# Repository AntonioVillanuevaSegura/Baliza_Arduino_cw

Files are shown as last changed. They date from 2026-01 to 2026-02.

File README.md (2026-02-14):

# Baliza_Arduino_cw
Modificacion del programa de EA7HG  por F4LEC , para simulacion ,

Posibilidad de cambiar WPM 
Cambio de mensaje linea 13 String mensaje = "";  //Mensaje a enviar por la baliza
Debug RS232

( entre comentarios esta el codigo para modo real , no simulacion ,  no probado )

Link a simulacion con el codigo C++ modificado 
https://wokwi.com/projects/454496346094658561

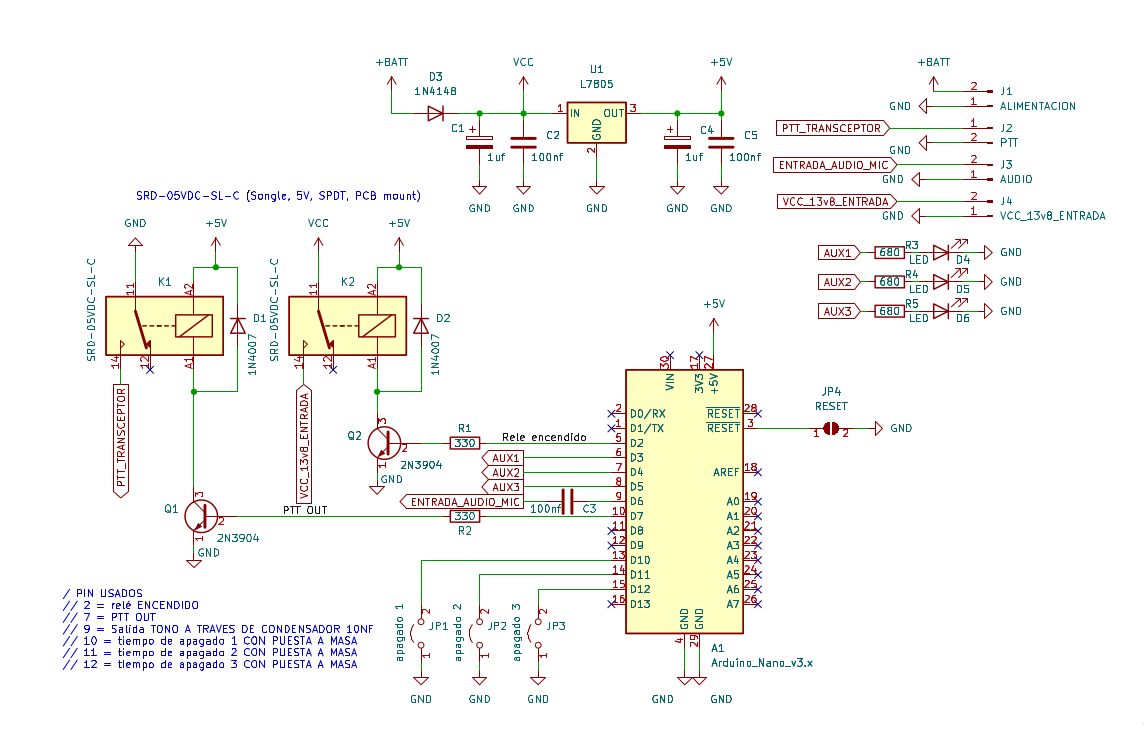
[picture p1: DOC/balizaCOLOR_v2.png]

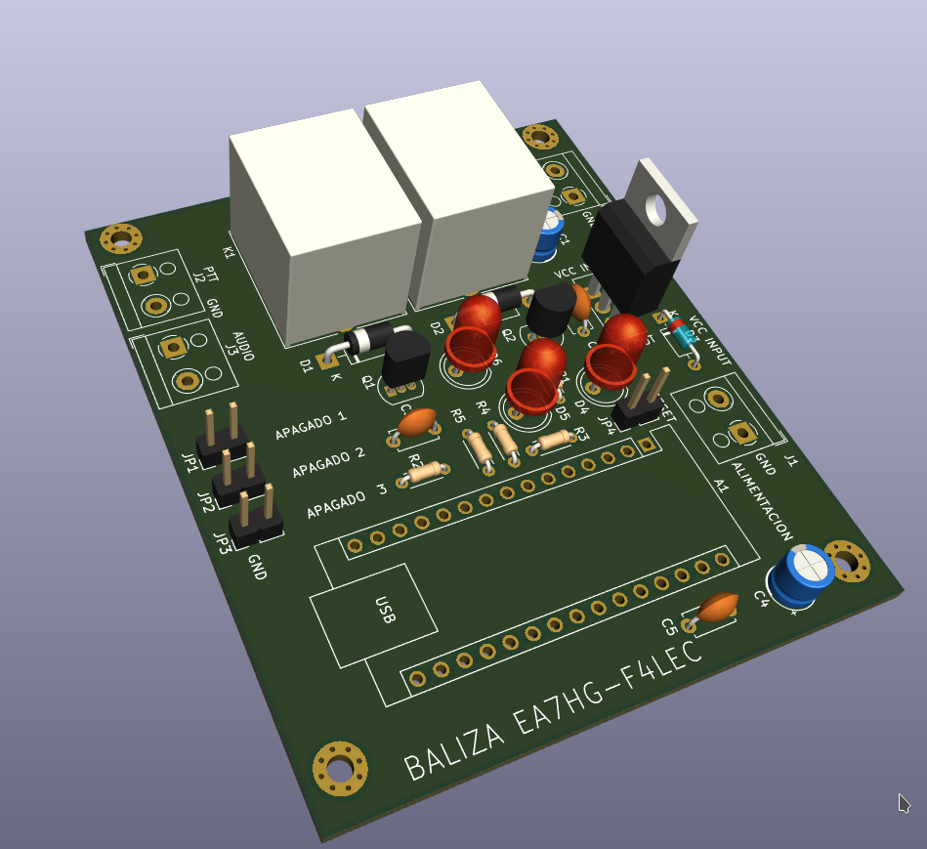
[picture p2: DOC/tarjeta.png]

Watch the video (https://youtu.be/UsDUSa7aJFM)

La tarjeta PCB tiene un diodo de proteccion de polaridad a la entrada
He previsto la PCB con 3 salidas adicionales con LED ,pero la base sigue siendo la misma 

La CPU es una Arduino nano , resistencia de 1/4 de W ....

Hay una carpeta GERBER con un fichero comprimido baliza.zip que es 
compatible con el formato de https://jlcpcb.com por ejemplo 

El tipo de rele que voy a utilizar 
PC, JQC-3F(T73), DC5V Bobine, SPDT, 7A 240VAC Bornes 5 broches
https://www.amazon.fr/dp/B074599SN8?ref=ppx_yo2ov_dt_b_fed_asin_title

Los conectores
5mm PCB Vis Connecteur, Bornier à Souder Vert, 2
https://www.amazon.fr/dp/B0DSBSXL47?ref=ppx_yo2ov_dt_b_fed_asin_title

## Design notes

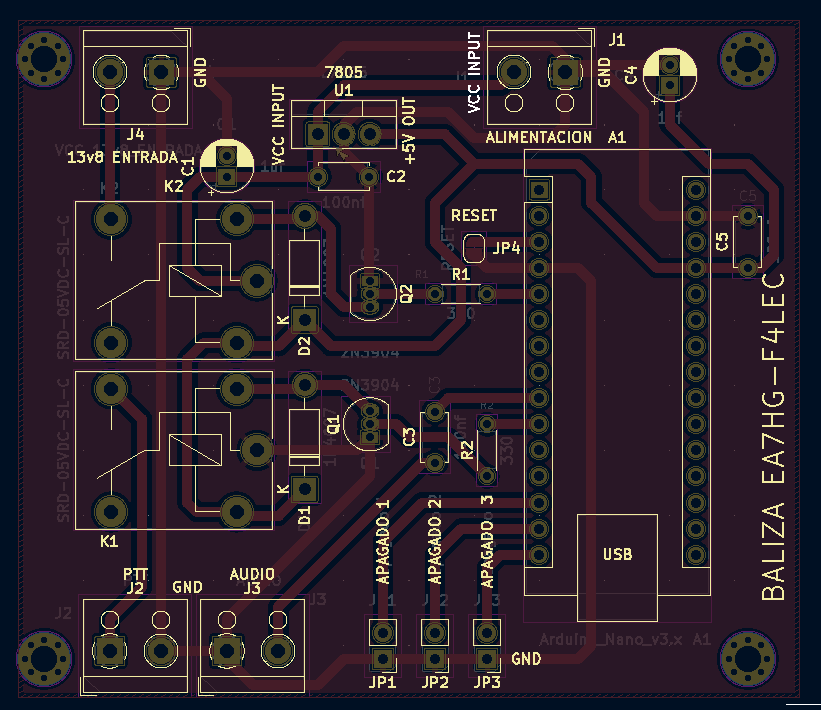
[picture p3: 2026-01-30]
DOC/tarjeta2.png

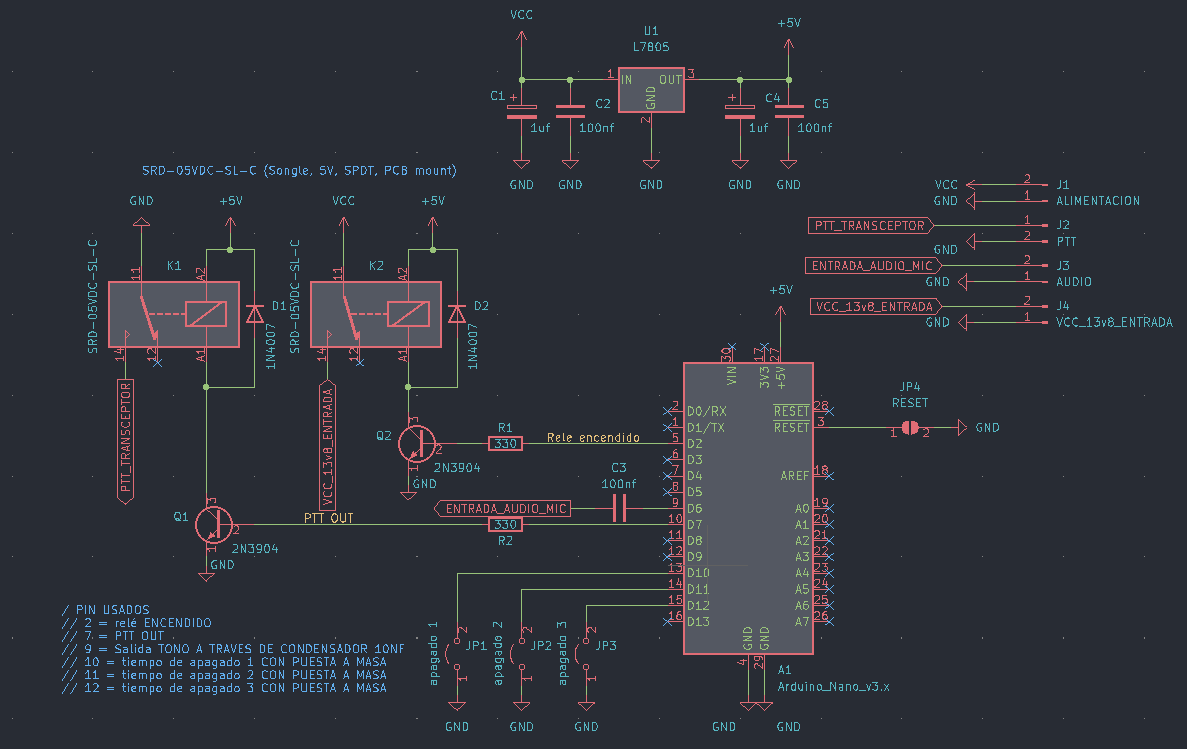
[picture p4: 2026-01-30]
DOC/balizaCOLOR.png

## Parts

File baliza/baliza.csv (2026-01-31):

Id | Référence | Boîtier | Quantité | Désignation | Fournisseur et réf
1 | D4,D6,D5 | LED_D5.0mm | 3 | LED
2 | U1 | TO-220-3_Vertical | 1 | L7805
3 | JP1 | PinHeader_1x02_P2.54mm_Vertical | 1 | apagado 1
4 | J2 | TerminalBlock_RND_205-00001_1x02_P5.00mm_Horizontal | 1 | PTT
5 | C4,C1 | CP_Radial_D5.0mm_P2.00mm | 2 | 1uf
6 | A1 | Arduino_Nano | 1 | Arduino_Nano_v3.x
7 | C3,C2,C5 | C_Disc_D4.7mm_W2.5mm_P5.00mm | 3 | 100nf
8 | K2,K1 | Relay_SPDT_Finder_36.11 | 2 | SRD-05VDC-SL-C
9 | Q1,Q2 | TO-92_Inline | 2 | 2N3904
10 | R3,R5,R4 | R_Axial_DIN0204_L3.6mm_D1.6mm_P5.08mm_Horizontal | 3 | 680
11 | D3 | D_DO-35_SOD27_P7.62mm_Horizontal | 1 | 1N4148
12 | R1,R2 | R_Axial_DIN0204_L3.6mm_D1.6mm_P5.08mm_Horizontal | 2 | 330
13 | JP3 | PinHeader_1x02_P2.54mm_Vertical | 1 | apagado 3
14 | D1,D2 | D_DO-41_SOD81_P10.16mm_Horizontal | 2 | 1N4007
15 | J1 | TerminalBlock_RND_205-00001_1x02_P5.00mm_Horizontal | 1 | ALIMENTACION
16 | JP4 | PinHeader_1x02_P2.54mm_Vertical | 1 | RESET
17 | J3 | TerminalBlock_RND_205-00001_1x02_P5.00mm_Horizontal | 1 | AUDIO
18 | JP2 | PinHeader_1x02_P2.54mm_Vertical | 1 | apagado 2
19 | J4 | TerminalBlock_RND_205-00001_1x02_P5.00mm_Horizontal | 1 | VCC_13v8_ENTRADA

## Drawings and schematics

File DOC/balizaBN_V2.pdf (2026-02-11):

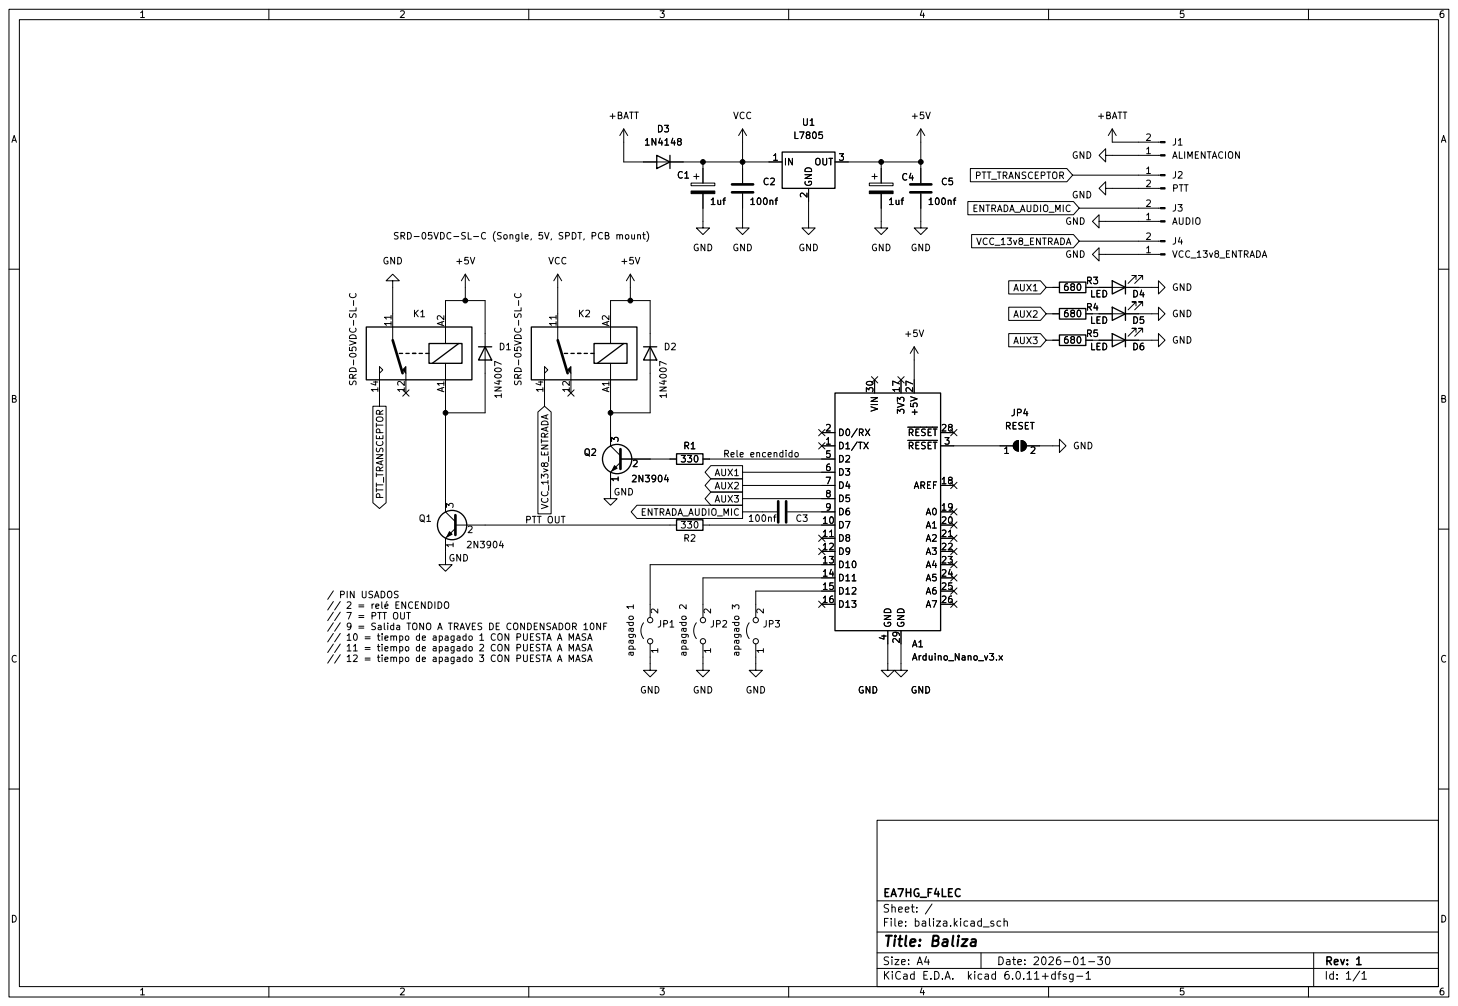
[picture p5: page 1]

Rele encendido PTT OUT

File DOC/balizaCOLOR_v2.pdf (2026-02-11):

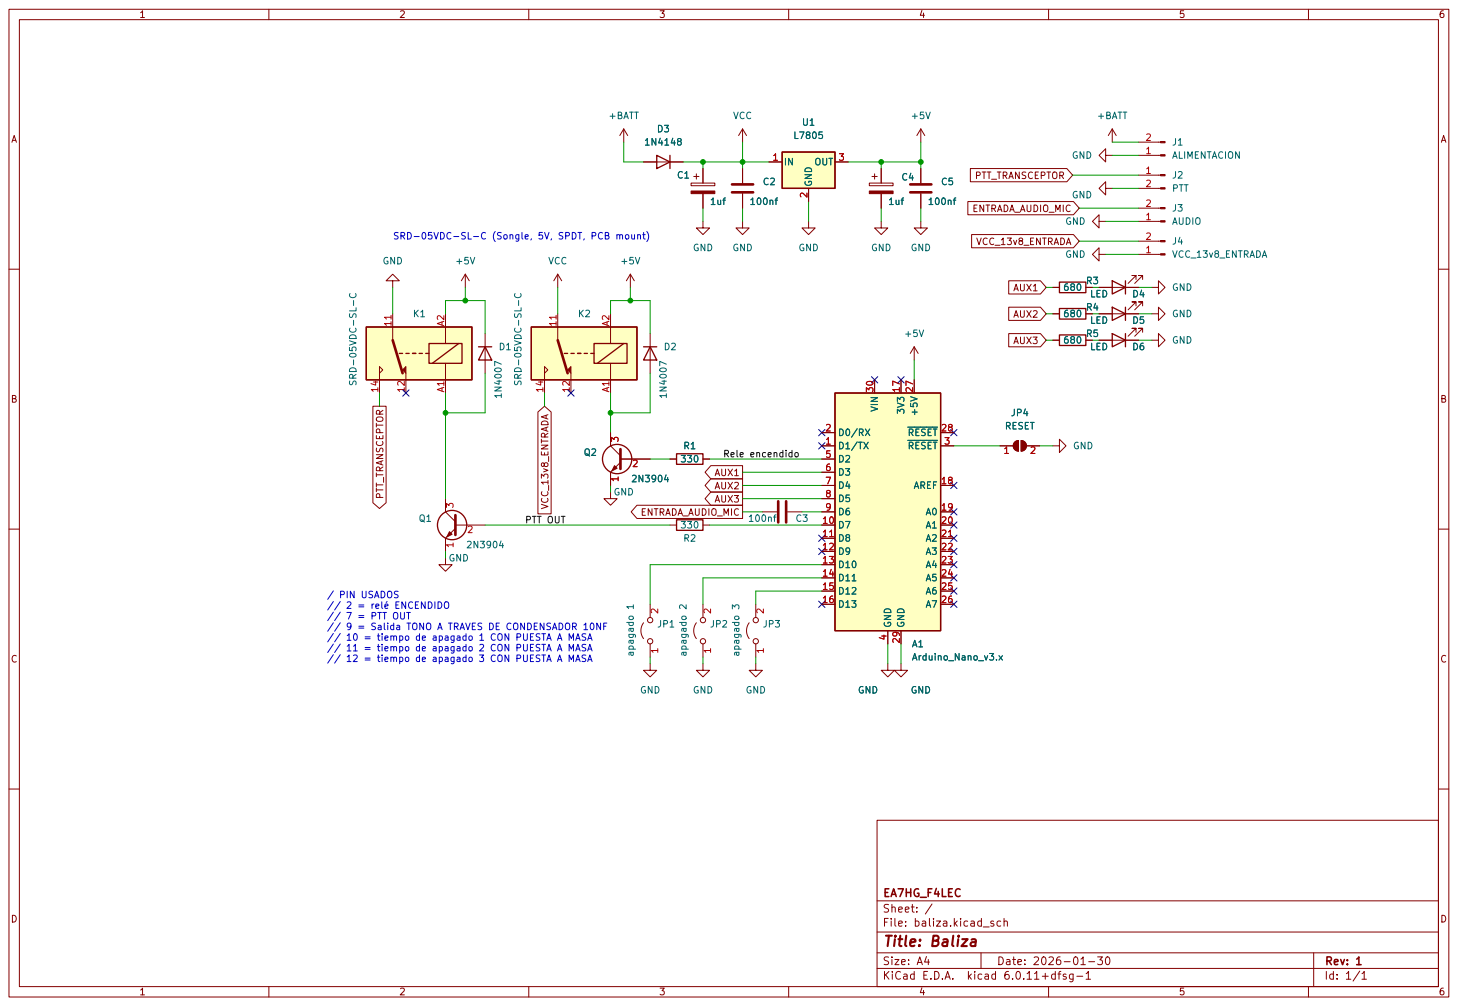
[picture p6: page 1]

Rele encendido PTT OUT

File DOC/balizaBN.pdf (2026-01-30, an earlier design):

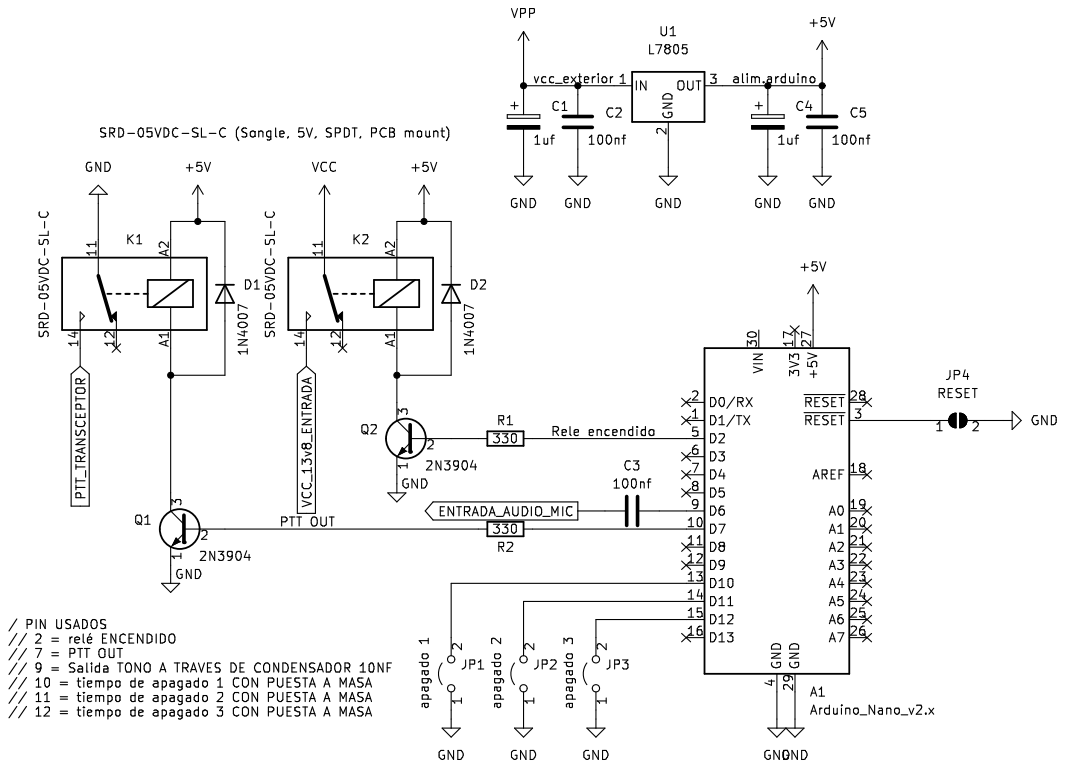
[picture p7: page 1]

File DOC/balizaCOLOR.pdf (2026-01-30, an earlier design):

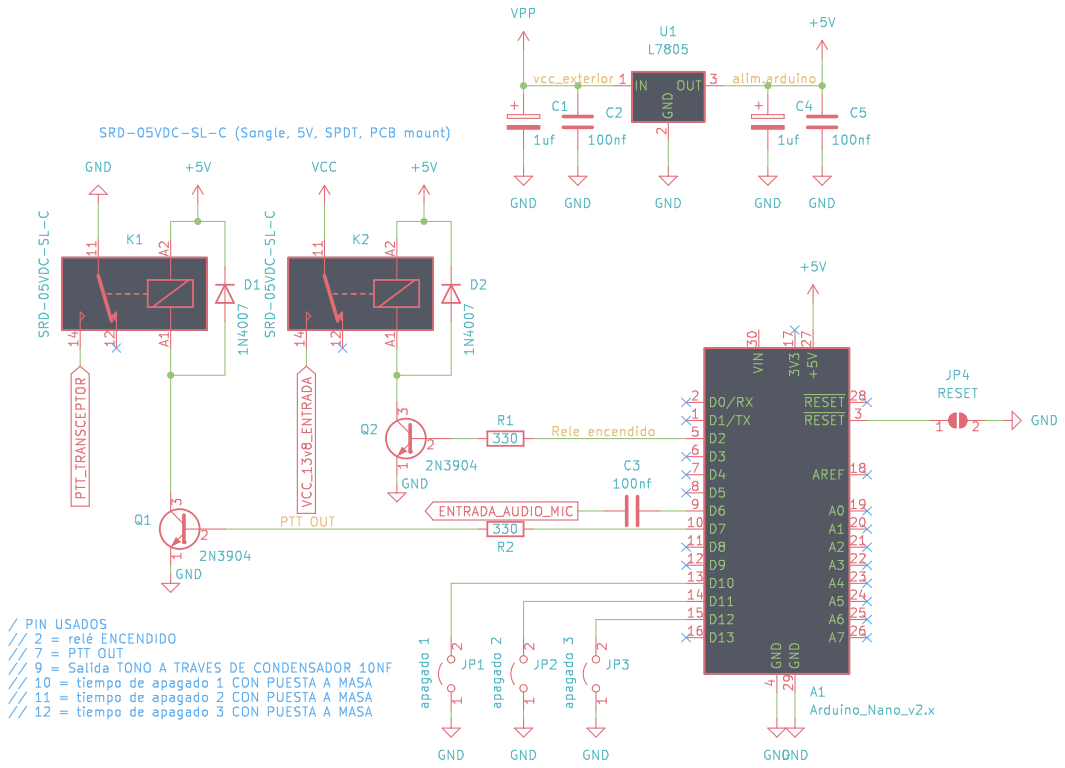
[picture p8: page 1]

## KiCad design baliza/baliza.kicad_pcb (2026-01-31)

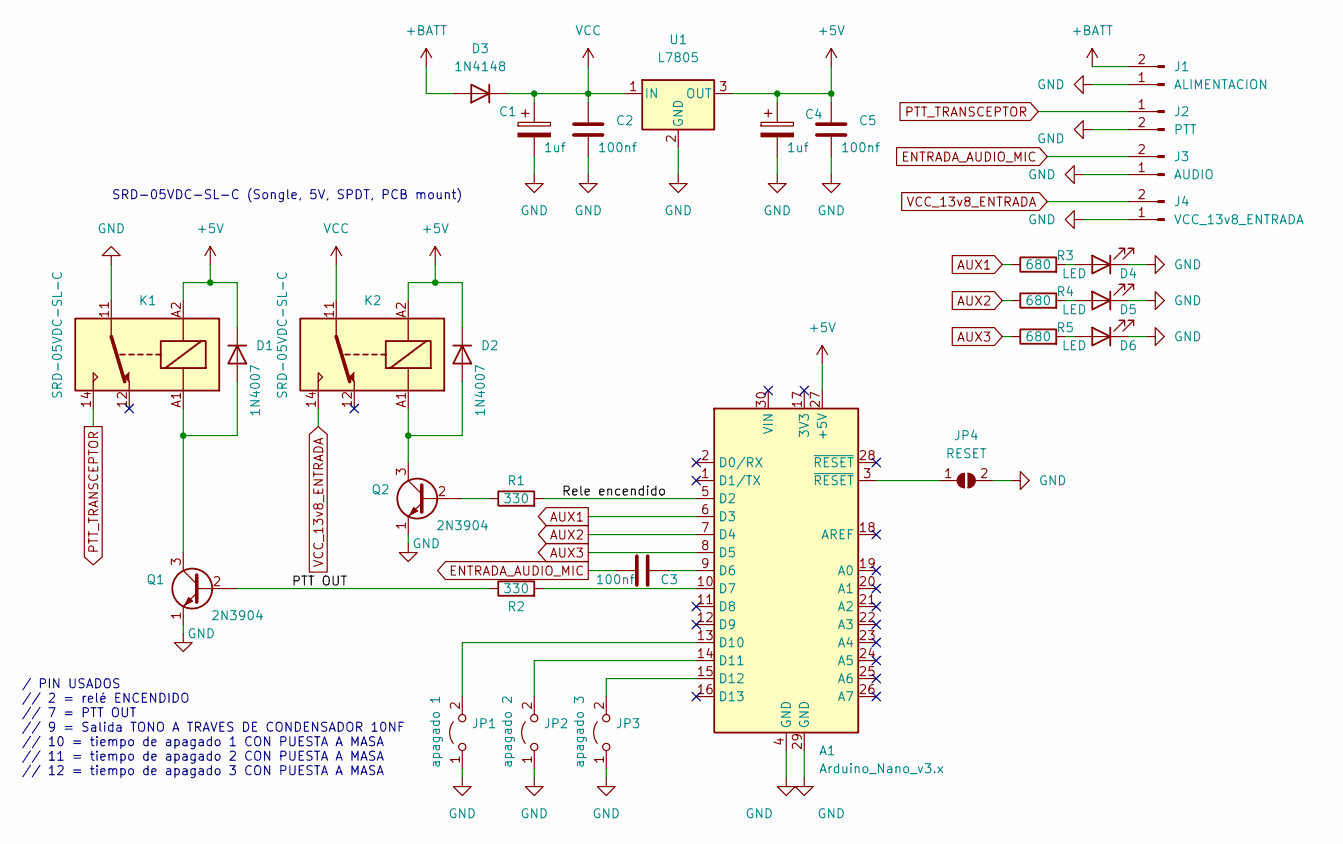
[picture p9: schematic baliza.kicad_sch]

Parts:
A1: Arduino_Nano_v3.x; Arduino_Nano
C1, C4: 1uf; CP_Radial_D5.0mm_P2.00mm
C2, C3, C5: 100nf; C_Disc_D4.7mm_W2.5mm_P5.00mm
D1, D2: 1N4007; D_DO-41_SOD81_P10.16mm_Horizontal
D3: 1N4148; D_DO-35_SOD27_P7.62mm_Horizontal
D4, D5, D6: LED; LED_D5.0mm
J1: ALIMENTACION; TerminalBlock_RND_205-00001_1x02_P5.00mm_Horizontal
J2: PTT; TerminalBlock_RND_205-00001_1x02_P5.00mm_Horizontal
J3: AUDIO; TerminalBlock_RND_205-00001_1x02_P5.00mm_Horizontal
J4: VCC_13v8_ENTRADA; TerminalBlock_RND_205-00001_1x02_P5.00mm_Horizontal
JP1: apagado 1; PinHeader_1x02_P2.54mm_Vertical
JP2: apagado 2; PinHeader_1x02_P2.54mm_Vertical
JP3: apagado 3; PinHeader_1x02_P2.54mm_Vertical
JP4: RESET; PinHeader_1x02_P2.54mm_Vertical
K1, K2: SRD-05VDC-SL-C; Relay_SPDT_Finder_36.11
Q1, Q2: 2N3904; TO-92_Inline
R1, R2: 330; R_Axial_DIN0204_L3.6mm_D1.6mm_P5.08mm_Horizontal
R3, R4, R5: 680; R_Axial_DIN0204_L3.6mm_D1.6mm_P5.08mm_Horizontal
U1: L7805; TO-220-3_Vertical

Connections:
+5V: A1.27 (+5V), C4.1, C5.1, D1.1 (K), D2.1 (K), K1.A2, K2.A2, U1.3 (OUT)
+BATT: D3.2 (A), J1.2
/PTT OUT: Q1.2 (B), R2.1
/Rele encendido: A1.5 (D2), R1.2
AUX1: A1.6 (D3), R3.1
AUX2: A1.7 (D4), R4.1
AUX3: A1.8 (D5), R5.1
ENTRADA_AUDIO_MIC: C3.1, J3.2
GND: A1.4 (GND), A1.29 (GND), C1.2, C2.2, C4.2, C5.2, D4.1 (K), D5.1 (K), D6.1 (K), J1.1, J2.2, J3.1, J4.1, JP1.1 (A), JP2.1 (A), JP3.1 (A), JP4.2 (B), K1.11, Q1.1 (E), Q2.1 (E), U1.2 (GND)
unnamed: A1.3 (~RESET), JP4.1 (A)
unnamed: A1.9 (D6), C3.2
unnamed: A1.10 (D7), R2.2
unnamed: A1.13 (D10), JP1.2 (B)
unnamed: A1.14 (D11), JP2.2 (B)
unnamed: A1.15 (D12), JP3.2 (B)
unnamed: D1.2 (A), K1.A1, Q1.3 (C)
unnamed: D2.2 (A), K2.A1, Q2.3 (C)
unnamed: D4.2 (A), R3.2
unnamed: D5.2 (A), R4.2
unnamed: D6.2 (A), R5.2
unnamed: Q2.2 (B), R1.1
PTT_TRANSCEPTOR: J2.1, K1.14
VCC: C1.1, C2.1, D3.1 (K), K2.11, U1.1 (IN)
VCC_13v8_ENTRADA: J4.2, K2.14

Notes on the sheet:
/ PIN USADOS // 2 = relé ENCENDIDO // 7 = PTT OUT // 9 = Salida TONO A TRAVES DE CONDENSADOR 10NF // 10 = tiempo de apagado 1 CON PUESTA A MASA // 11 = tiempo de apagado 2 CON PUESTA A MASA // 12 = tiempo de apagado 3 CON PUESTA A MASA
SRD-05VDC-SL-C (Songle, 5V, SPDT, PCB mount)

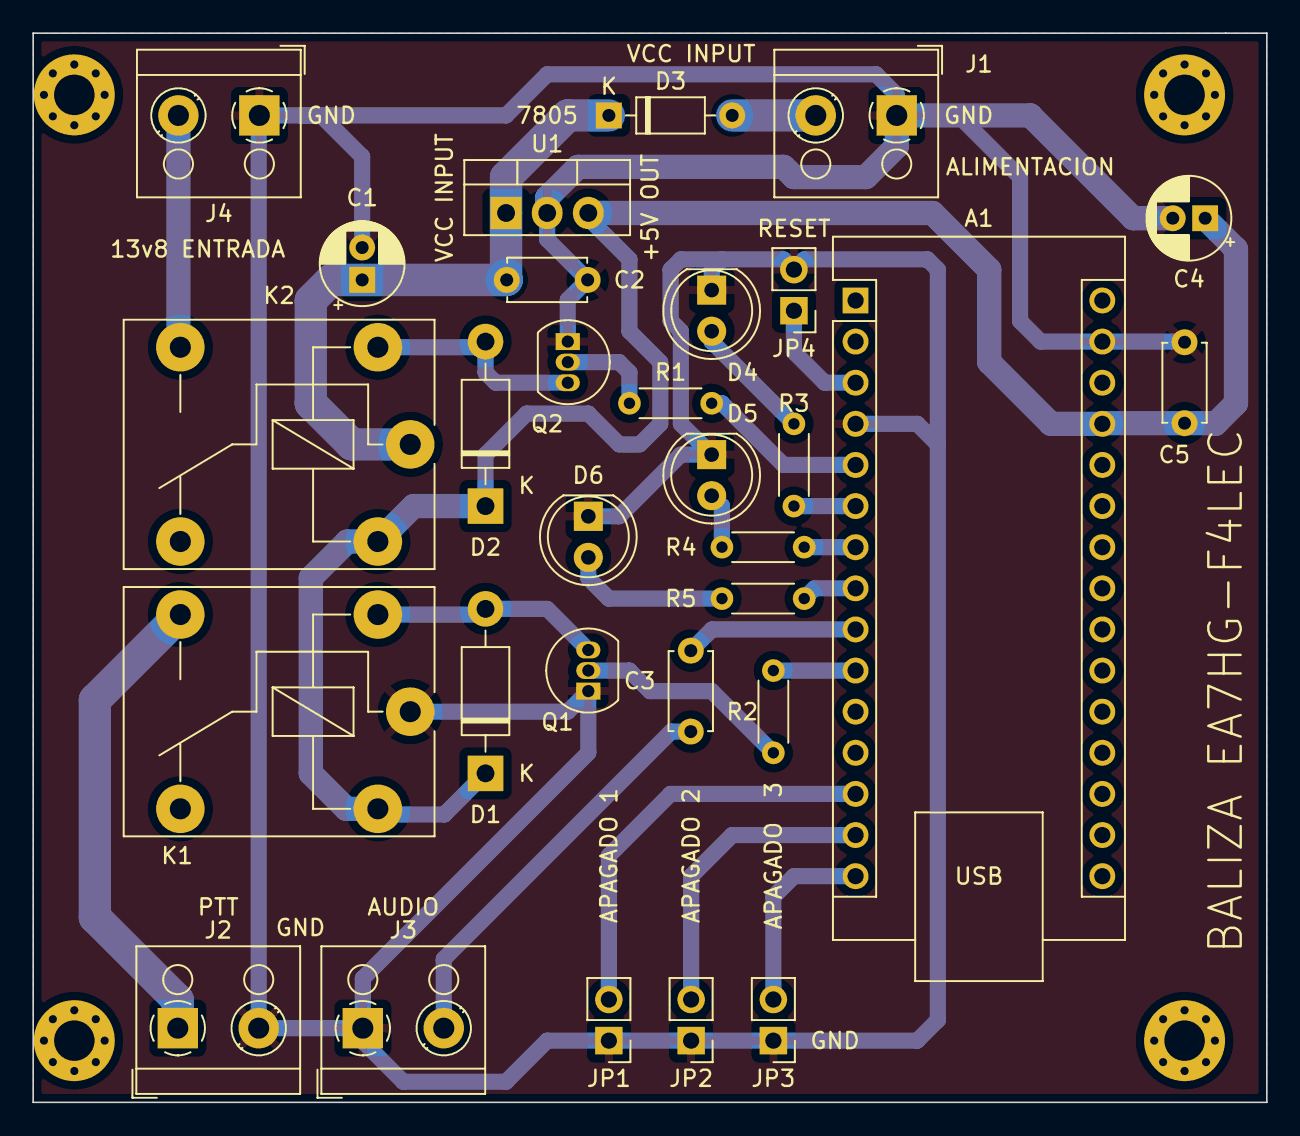
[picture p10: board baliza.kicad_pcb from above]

Board: 2 copper layers, 76.2 x 66.0 mm, 30 parts (0 on the bottom side), 24 nets.

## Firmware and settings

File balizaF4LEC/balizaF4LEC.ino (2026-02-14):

//////////////////////////////////////////////////
// PROGRAMA DE BALIZA, CACERÍAS DE ZORRO, ETC  //
// EA7HG, 2025 Software libre                   //
// MODIFICACION F4LEC SIMULACION +WPM+debug		//
//////////////////////////////////////////////////

// PIN USADOS
// 2 = relé ENCENDIDO
// 7 = PTT OUT  
// 9 = SALIDA TONO A TRAVES DE CONDENSADOR 10NF
//////////////////////////////////////////////////

String mensaje = "V V V DE F4LEC ZORRO K";  //Mensaje a enviar por la baliza
int frecuencia =800; //Frecuencia CW 
int WPM = 30;  // Velocidad en palabras por minuto

// Define variable con 30 s. Tiempo por defecto de espera
unsigned long tiempo_disparo = 30;
// Define variable para iniciar tiempos
unsigned long tiempo_inicial = 0;
// Define tiempo del punto en morse. La raya multiplica por 3

unsigned int punto = 167;

// Define los pines para mejor lectura de código
#define ENCENDIDO 2
#define PTT 7
#define SALIDA 6 //PIN FISICO 9 ES D6 en arduino NANO

//Entradas retardo 2^8 posibilidades
#define RETARDO_1 10
#define RETARDO_2 11
#define RETARDO_3 12

//Leds salida auxiliares
#define LED_1 3
#define LED_2 4
#define LED_3 5

//Creamos un diccionario KEY:VALUE donde cada signo  tiene su correspondencia CW

const char* key[] = {
  "A", "B", "C", "D", "E", "F", "G", "H", "I", "J",
  "K", "L", "M", "N", "O", "P", "Q", "R", "S", "T",
  "U", "V", "W", "X", "Y", "Z",
  "0", "1", "2", "3", "4", "5", "6", "7", "8", "9", " "
};

const char* value[] = {
  ".-", "-...", "-.-.", "-..", ".", "..-.", "--.", "....", "..", ".---",
  "-.-", ".-..", "--", "-.", "---", ".--.", "--.-", ".-.", "...", "-",
  "..-", "...-", ".--", "-..-", "-.--", "--..",
  "-----", ".----", "..---", "...--", "....-", ".....", 
  "-....", "--...", "---..", "----.", "-----",
  " "
};

void setup() {

	punto =calcularTimingCW(WPM);
	Serial.begin(9600);  // Debug serie
	Serial.println("Velocidad punto " + String(punto) + " ms");

	// pin 2 configurado para SALIDA
	pinMode(ENCENDIDO, OUTPUT);
	digitalWrite(ENCENDIDO, LOW);

	// pin 7 configurado para SALIDA
	pinMode(PTT, OUTPUT);
	digitalWrite(PTT, LOW);

	// pin 9 configurado para SALIDA tono
	pinMode(SALIDA, OUTPUT);

	//D3 D4 D5 LEDs salidas auxiliares PCB  
	pinMode(LED_1, OUTPUT);
	pinMode(LED_2, OUTPUT);
	pinMode(LED_3, OUTPUT);

	//pin 10,11,12 entrada configura apagado 
	pinMode(RETARDO_1, INPUT_PULLUP);
	pinMode(RETARDO_2, INPUT_PULLUP);
	pinMode(RETARDO_3, INPUT_PULLUP);
	

	/*2³ =8 posibilidades de retardo 
	Switch 10	Switch 11	Switch 12	Bits (1=ON)	tiempo_disparo
	OFF	OFF	OFF	000 = 0	0ms
	ON	OFF	OFF	001 = 1	15ms
	OFF	ON	OFF	010 = 2	30ms
	ON	ON	OFF	011 = 3	45ms
	OFF	OFF	ON	100 = 4	60ms
	ON	OFF	ON	101 = 5	75ms
	OFF	ON	ON	110 = 6	90ms
	ON	ON	ON	111 = 7	105ms	
	*/
	tiempo_disparo = (digitalRead(RETARDO_1)|digitalRead(RETARDO_2)|digitalRead(RETARDO_3))*15;
	Serial.println("Retardo " +String (tiempo_disparo) + " ms");
	Activar_Baliza();
	tiempo_inicial = millis();
}

void loop() {
  // al finalizar tiempo de espera activa la baliza
  if ((millis() - tiempo_inicial) >= (tiempo_disparo * 1000)) {
    Activar_Baliza();
  }
}

void Activar_Baliza() {
	
	led_ON (LED_3);
  // Activa relé ENCENDIDO transceptor o emisor
  digitalWrite(ENCENDIDO, HIGH);
  // Espera 1000 ms (1 segundo) antes de activar el PTT
  delay(1000);
  // Activa relé para activar PTT
  digitalWrite(PTT, HIGH);
  delay(250); // Espera 250ms (1/4 segundo)
  
  //Envio Mensaje , recorre el mensaje a enviar por la baliza
	for (int i = 0; i < mensaje.length(); i++) {
		playCW ( getCwCode ( mensaje[i] ) );
	}
  
  // Desactiva relé del PTT
  digitalWrite(PTT, LOW);
  // espera 500 ms (1/2 segundo)
  delay(500);
  // Apaga transceptor o emisor
  digitalWrite(ENCENDIDO, LOW);
  // Inicia nuevamente el temporizador de espera
  tiempo_inicial = millis();
  led_OFF (LED_3);
}

// obtiene el codigo CW de un signo , p.e A retorna .-
String getCwCode(char caracter) { 
	Serial.print (caracter);//Debug caracter
	if (caracter==' '){return " ";}//Retorna espacio 

	//Recorre la matriz de key creando indices 
	for (int index=0;index<(sizeof(key)/sizeof(key[0]));index++){//Recorre key
		
		if ( key[index][0] ==  toupper(caracter) ){
			return value[index];
		}
	}
	return "";
}

//Funciones auxiliares para activar leds auxiliares
void led_ON(int led){
	digitalWrite(led,HIGH);
}

void led_OFF(int led){
	digitalWrite(led,LOW);
}

//Play sonido CW ,del simbolo 
void playCW (String cw){
	Serial.print("(" +cw+ ") ");
	//Recorre el equivalente CW , puntos , rayas y espacios del CW
	for (int index=0;index<cw.length();index++){

		//ESTE CODIGO ES PARA MODO REAL NO PROBADO PERO DEBE SER ALGO ASI

		
		if (cw.charAt(index) =='.'){tone(SALIDA, frecuencia);led_ON (LED_1);delay(punto); noTone(SALIDA); delay(punto * 3);led_OFF (LED_1);}//punto .
		else if (cw.charAt(index) =='-'){tone(SALIDA, frecuencia);led_ON (LED_2);delay(punto * 3); noTone(SALIDA); delay(punto / 2);led_OFF (LED_2);}//raya _
		else { delay(punto); }//Espacio	entre elementos punto raya
		delay( (punto * 2) );			
		
		
		//ESTE CODIGO FUNCIONA EN MODO SIMULACION CON UN BUZZER SIMULADO 
   /*
		if (cw.charAt(index) =='.'){tone(SALIDA, frecuencia,punto);led_ON (LED_1) ;delay( (punto) + 10); led_OFF (LED_1);}//punto .
		else if (cw.charAt(index) =='-'){tone(SALIDA, frecuencia,punto * 3);delay( (punto * 3) + 10);led_OFF (LED_2);}//raya _
		else { delay(punto); }//Espacio	entre elementos punto raya
		delay( (punto * 2) );		
    */
	}
	led_OFF (LED_1);
	led_OFF (LED_2);	
	delay (punto*2);
}

//Calcula el tiempo de un punto en funcion de los WPM seleccionados
unsigned int calcularTimingCW(int wpm) {
  return (unsigned int)(1320.0 / wpm);
}

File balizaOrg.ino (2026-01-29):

//////////////////////////////////////////////////
// PROGRAMA DE BALIZA, CACERÍAS DE ZORRO, ETC  //
// EA7HG, 2025 Software libre                   //
//////////////////////////////////////////////////

// PIN USADOS
// 2 = relé ENCENDIDO
// 7 = PTT OUT  
// 9 = Salida TONO A TRAVES DE CONDENSADOR 10NF
// 10 = tiempo de apagado 1 CON PUESTA A MASA
// 11 = tiempo de apagado 2 CON PUESTA A MASA
// 12 = tiempo de apagado 3 CON PUESTA A MASA
//////////////////////////////////////////////////

// Define variable con 30 s. Tiempo por defecto de espera
unsigned long tiempo_disparo = 30;
// Define variable para iniciar tiempos
unsigned long tiempo_inicial = 0;
// Define tiempo del punto en morse. La raya multiplica por 3
unsigned int punto = 167;

// Define los pines para mejor lectura de código
#define Encendido 2
#define PTT 7
#define Salida 9

void setup() {
  // pin 2 configurado para salida
  pinMode(Encendido, OUTPUT);
  digitalWrite(Encendido, LOW);
  
  // pin 7 configurado para salida
  pinMode(PTT, OUTPUT);
  digitalWrite(PTT, LOW);
  
  // pin 9 configurado para salida tono
  pinMode(Salida, OUTPUT);
  
  //pin 10 configurado como entrada para tiempo de apagado 1
  pinMode(10, INPUT_PULLUP);
  //pin 11 configurado como entrada para tiempo de apagado 2
  pinMode(11, INPUT_PULLUP);
  //pin 12 configurado como entrada para tiempo de apagado 3
  pinMode(12, INPUT_PULLUP);
  
  // Si pin 10 se pone a tierra (GND) -> tiempo 45 segundos
  if (digitalRead(10) == LOW) tiempo_disparo = 45;
  // Si pin 11 se pone a tierra (GND) -> tiempo 60 segundos  
  if (digitalRead(11) == LOW) tiempo_disparo = 60;
  // Si pin 12 se pone a tierra (GND) -> tiempo 90 segundos
  if (digitalRead(12) == LOW) tiempo_disparo = 90;
  
  // Emite por primera vez el mensaje de la baliza
  Activar_Baliza();
  // se inicia el tiempo de espera
  tiempo_inicial = millis();
}

void loop() {
  // al finalizar tiempo de espera activa la baliza
  if ((millis() - tiempo_inicial) >= (tiempo_disparo * 1000)) {
    Activar_Baliza();
  }
}

void Activar_Baliza() {
  // Activa relé encendido transceptor o emisor
  digitalWrite(Encendido, HIGH);
  // Espera 1000 ms (1 segundo) antes de activar el PTT
  delay(1000);
  // Activa relé para activar PTT
  digitalWrite(PTT, HIGH);
  delay(250); // Espera 250ms (1/4 segundo)
  
  // Emite 3 V seguidas (V = ...-)
  for (int ab = 0; ab < 3; ab++) {
    Caracter(9);
  }
  // tiempo para espacio en blanco
  delay(punto * 3);
  
  // Emite DEEA7URJRZORROK
  Caracter(11); // D
  Caracter(4);  // E
  delay(punto * 3);
  Caracter(4);  // E
  Caracter(5);  // A
  Caracter(6);  // 7
  Caracter(7);  // U
  Caracter(3);  // R
  Caracter(8);  // J
  delay(1000);
  Caracter(1);  // Z
  Caracter(2);  // O
  Caracter(3);  // R
  Caracter(3);  // R
  Caracter(2);  // O
  Caracter(10); // K
  
  // Desactiva relé del PTT
  digitalWrite(PTT, LOW);
  // espera 500 ms (1/2 segundo)
  delay(500);
  // Apaga transceptor o emisor
  digitalWrite(Encendido, LOW);
  // Inicia nuevamente el temporizador de espera
  tiempo_inicial = millis();
}

void Caracter(int num) { // Genera tono de letra o número
  if (num == 1) { // Letra Z --**
    tone(Salida, 800); delay(punto * 3); noTone(Salida); delay(punto / 2);
    tone(Salida, 800); delay(punto * 3); noTone(Salida); delay(punto / 2);
    tone(Salida, 800); delay(punto); noTone(Salida); delay(punto / 2);
    tone(Salida, 800); delay(punto); noTone(Salida); delay(punto * 3);
  }
  if (num == 2) { // Letra O ***
    for (int ab = 0; ab < 3; ab++) {
      tone(Salida, 800); delay(punto * 3); noTone(Salida); delay(punto / 2);
    }
    delay(punto * 3);
  }
  if (num == 3) { // Letra R *.-.
    tone(Salida, 800); delay(punto); noTone(Salida); delay(punto / 2);
    tone(Salida, 800); delay(punto * 3); noTone(Salida); delay(punto / 2);
    tone(Salida, 800); delay(punto); noTone(Salida); delay(punto * 3);
  }
  if (num == 4) { // Letra E *
    tone(Salida, 800); delay(punto); noTone(Salida); delay(punto * 3);
  }
  if (num == 5) { // Letra A *-
    tone(Salida, 800); delay(punto); noTone(Salida); delay(punto / 2);
    tone(Salida, 800); delay(punto * 3); noTone(Salida); delay(punto * 3);
  }
  if (num == 6) { // Número 7 **---
    for (int ab = 0; ab < 2; ab++) {
      tone(Salida, 800); delay(punto * 3); noTone(Salida); delay(punto / 2);
    }
    for (int ab = 0; ab < 3; ab++) {
      tone(Salida, 800); delay(punto); noTone(Salida); delay(punto / 2);
    }
    delay(punto * 3);
  }
  if (num == 7) { // Letra U **-
    for (int ab = 0; ab < 2; ab++) {
      tone(Salida, 800); delay(punto); noTone(Salida); delay(punto / 2);
    }
    tone(Salida, 800); delay(punto * 3); noTone(Salida); delay(punto * 3);
  }
  if (num == 8) { // Letra J *---
    tone(Salida, 800); delay(punto); noTone(Salida); delay(punto / 2);
    for (int ab = 0; ab < 3; ab++) {
      tone(Salida, 800); delay(punto * 3); noTone(Salida); delay(punto / 2);
    }
    delay(punto * 3);
  }
  if (num == 9) { // Letra V ...-
    for (int ab = 0; ab < 3; ab++) {
      tone(Salida, 800); delay(punto); noTone(Salida); delay(punto / 2);
    }
    tone(Salida, 800); delay(punto * 3); noTone(Salida); delay(punto * 3);
  }
  if (num == 10) { // Letra K -.- 
    tone(Salida, 800); delay(punto * 3); noTone(Salida); delay(punto / 2);
    tone(Salida, 800); delay(punto); noTone(Salida); delay(punto / 2);
    tone(Salida, 800); delay(punto * 3); noTone(Salida); delay(punto * 3);
  }
  if (num == 11) { // Letra D -..
    tone(Salida, 800); delay(punto * 3); noTone(Salida); delay(punto / 2);
    for (int ab = 0; ab < 2; ab++) {
      tone(Salida, 800); delay(punto); noTone(Salida); delay(punto / 2);
    }
    delay(punto * 3);
  }
}

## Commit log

2026-01-30 esquemas pdf de kicad
2026-01-31 anadir LEDs auxiliares, pistas en cara inferior
    [baliza.kicad_pcb, baliza.kicad_sch]
2026-01-31 fotos gerbers
    [baliza.kicad_pcb]
2026-02-11 version pcb
2026-02-11 version 2 simulacion PCB
2026-02-14 SALIDA 6 es D6 pin fisico 9 de arduino NANO salida audio
